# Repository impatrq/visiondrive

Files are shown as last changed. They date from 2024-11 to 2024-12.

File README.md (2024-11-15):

# VISION DRIVE: Innovacion en movimiento

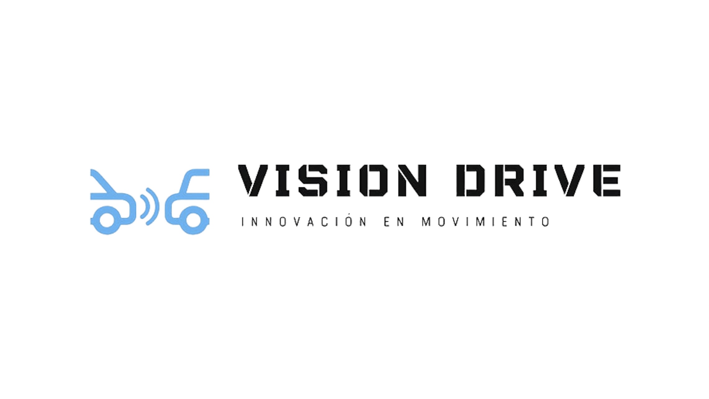
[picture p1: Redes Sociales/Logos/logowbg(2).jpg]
Descripción de la imagen


## Descripción del Proyecto

**Vision Drive** es un sistema diseñado para mejorar la seguridad y comodidad en la conducción mediante funciones de control de velocidad adaptativo y frenado de emergencia. Su propósito es reducir el esfuerzo del conductor y ofrecer un manejo más seguro.

## Características principales

- **Sistema de Control de Crucero Adaptativo (ACC)**: Permite al vehículo mantener una velocidad constante, ajustándose automáticamente en función de la distancia segura respecto a otros vehículos detectados en la misma vía.
- **Sistema de Emergencia Integrado**:  Este sistema monitorea el entorno en todo momento mientras el vehículo está en marcha. En situaciones de riesgo, como una frenada brusca de otro vehículo o la detección de una colisión inminente, el sistema activa el frenado automático.
- **Interfaz Adaptable**: Personalización según las necesidades del usuario.

## Tecnologías utilizadas

- **Sensor LiDar**: Para identificar la distancia del vehiculo de enfrente.
- **Sensor de Velocidad**: Para identificar la velocidad del vehiculo. 
- **ESP32** Para el procesamiento de datos.
- **C++ y Arduino IDE** Para el desarrollo del software 
- **Diseño PCB personalizado** para la integración de los componentes.
- **Motor Paso a Paso** Para el accionado del freno automatico.

## Estructura del Equipo

| Integrante | Responsabilidad |
|---|---|
| **Ponce Thiago** | Documentación y asistencia técnica |
| **Racioppi Giuliano**  | Programacion de los sensores |  
| **Meleri Thiago** | Diseño de las placas PCB |
| **Mazzoni Teo** | Código para los motores |
| **Suarez Simon** | Marketing |
| **Garofalo Thiago** | Diseño web y estructura |

## Contacto

- **Correo**: [Visiondriveimpa@gmail.com](mailto:visiondriveimpa@gmail.com)
- **Instagram**: (https://www.instagram.com/visiondrive24/)
- **Linktree**: (https://linktr.ee/visiondrive_2024)

*VISION DRIVE 2024 - Todos los derechos reservados*

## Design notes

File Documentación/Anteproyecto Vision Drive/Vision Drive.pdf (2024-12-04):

Escuela de Educación Técnica Nº7
Taller Regional Quilmes
Prácticas Profesionalizantes: Especialidad Aviónica

# VISION Drive

### Presentación de anteproyecto

Título del proyecto:

Elegimos como nombre del proyecto “VISION Drive” (Vehículo Inteligente con Sistemas Integrados de Orientación y Navegación) ya que transmite la esencia de un sistema de conducción avanzado que utiliza la visión como metáfora de la anticipación y la inteligencia del sistema, proporcionando a los conductores una herramienta poderosa para una conducción más segura y eficiente.

Integrantes:

- GAROFALO QUINTANA, Thiago: thiagogarofaloquintana@impatrq.com
- MAZZONI, Teo Jerónimo: teogeronimomazzoni@impatrq.com
- MELERI, Thiago Joaquín: thiagojoaquinmeleri@impatrq.com
- PONCE, Thiago Caín: thiagocainponce@impatrq.com
- RACIOPPI, Giuliano Daniel: giulianodanielracioppi@impatrq.com
- SUAREZ TUDISCA, Simón: simonsuareztudisca@impatrq.com
Objetivo del proyecto:

El objetivo principal del proyecto es crear un sistema capaz de mejorar la seguridad y la comodidad en la conducción de los vehículos de transporte, mediante la implementación de un sistema de control de crucero adaptativo y un sistema de emergencia integrado.

VISION Drive permitirá a los vehículos mantener una velocidad constante y segura en las vías de tránsito, ajustando automáticamente su velocidad para mantener una distancia de seguridad con respecto a los autos que se encuentren delante. Esto reduce la fatiga del conductor y mejora la eficiencia del viaje al adaptarse a las condiciones del tráfico de manera inteligente.

Este tiene un sistema de emergencia integrado el cual busca proporcionar una seguridad al detectar situaciones de riesgo inminente, como colisiones potenciales o frenadas bruscas de otros vehículos. En dichos casos, el sistema activará medidas de seguridad automáticas, como el frenado de emergencia o la emisión de alertas visuales y auditivas, para ayudar a prevenir accidentes o mitigar sus efectos.

Este enfoque busca contribuir a la mejora continua de la seguridad vial y la experiencia de transporte en entornos urbanos y de carretera.

Utilidades de el proyecto:

Las utilidades del proyecto de sistema de control de crucero adaptativo para el vehículo y sistema de emergencia pueden ser diversas y beneficiosas para diferentes sectores de la sociedad y entidades estratégicas:

Usuarios de VISION Drive:

- Facilita la conducción y reduce la fatiga del conductor evitando que el mismo esté pendiente a la aceleración y frenado del vehículo manteniendo una velocidad constante automáticamente. siendo muy útil en congestiones vehiculares de autopistas y calles mejorando la experiencia de manejo
- Incrementa la seguridad al ajustar automáticamente la velocidad en función de la distancia de seguimiento preventiva, ayudando a evitar accidentes por distracciones y acortando los tiempos de reacción
- El sistema de emergencia proporciona una alerta de seguridad al detectar y responder rápidamente a situaciones de riesgo, como colisiones potenciales, brindando tranquilidad a los ocupantes del vehículo

Entidades de transporte y logística:

- Mejora la eficiencia y la seguridad de las flotas de vehículos comerciales al reducir el riesgo de accidentes.

- Reduce los costos asociados con accidentes y mantenimiento al prevenir situaciones de emergencia o minimizando los daños recibidos .

Entidades de seguridad vial y reguladoras:

- Contribuye a la reducción de accidentes de tráfico y lesiones relacionadas al mejorar la capacidad de respuesta y la seguridad en la conducción.

Entidades de investigación y desarrollo tecnológico:

- Impulsa la innovación en el campo de la seguridad automotriz al integrar tecnologías avanzadas como el control de crucero adaptativo y los sistemas de emergencia en vehículos de transporte.

Descripción del funcionamiento:

Sistema de Control de Crucero Adaptativo (ACC):

Vision Drive comenzará a funcionar cuando el usuario seleccione la velocidad a la que quiere ir y presione el botón de funcionamiento

El sistema utilizará sensores (LiDAR) para detectar vehículos en la misma vía y calculará la distancia y la velocidad relativa con respecto a ellos.

Basándose en la información de los sensores, Vision drive ajustará automáticamente la velocidad del vehículo para mantener una distancia segura con los vehículos delanteros.

esta distancia de seguridad se estará constantemente monitoreando y dependiendo la velocidad a la que vaya el vehículo se seguirá una distancia correspondiente

El ACC también estará preparado para desactivarse automáticamente si el conductor aplica los frenos o interviene manualmente en la aceleración

Sistema de Emergencia Integrado:
- El sistema de emergencia estará activo en todo momento mientras el vehículo esté en funcionamiento.
- constantemente estará monitoreando los vehículos de enfrente y en caso de ocurrir una frenada brusca por parte del vehículo de enfrente, se ejecutará un frenado de emergencia con respuesta rápida.
- Cuando se detecte una situación de emergencia, el sistema activará automáticamente medidas de seguridad, como el frenado de emergencia, para evitar o mitigar el impacto de un accidente.
- El sistema de emergencia estará diseñado para ser robusto y confiable, minimizando los falsos positivos y asegurando una respuesta rápida y efectiva ante situaciones de peligro

Integración y Operatividad:
- Ambos sistemas, el ACC y el sistema de emergencia, estarán completamente integrados en el Melex, utilizando una arquitectura de control centralizada y eficiente.
- El software de ambos sistemas será altamente adaptable y configurable para ajustarse a las preferencias y necesidades específicas del conductor.
- Se proporcionará capacitación a los conductores para comprender y utilizar correctamente las funciones del ACC y el sistema de emergencia, así como para saber cómo actuar en caso de una intervención manual necesaria o una situación de emergencia.

En conclusión, la funcionalidad del proyecto se centra en implementar tecnologías avanzadas que mejoren la seguridad y la comodidad en la conducción del Melex, garantizando una operación efectiva y confiable del sistema de control de crucero adaptativo y el sistema de emergencia integrado.

Análisis de factibilidad:

Alumno 1: SUAREZ TUDISCA, Simón

- Diseño:
- Lista de Requisitos: Su primera tarea será elaborar una lista detallada de todos los elementos necesarios para el proyecto. Esto incluirá componentes técnicos como el sensor Lidar, así como también elementos de diseño como el logotipo, la estructura de la página web y cualquier otro recurso necesario para el funcionamiento y la presentación del proyecto.
- Diseño de la Estructura: Se encargará de diseñar la estructura general del proyecto, incluyendo la arqmfy funcionalidad de la página web, y la integración de elementos de marketing como banners o material promocional.
- Diseño del Logotipo: Será responsable de crear el diseño del logotipo del proyecto, asegurándose de que refleje adecuadamente la identidad y los valores del mismo.
- Marketing: Colaborará en la estrategia de marketing del proyecto, contribuyendo con ideas y diseñando material promocional, como folletos, carteles, redes sociales, etc., para dar a conocer el proyecto y sus beneficios de manera efectiva.

Alumno 2: RACIOPPI, Giuliano Daniel
Alumno 3: MELERI, Thiago Joaquín
- La estructura: Reacondicionamiento de los dos melex para su correcto funcionamiento.
Problemas que ya tenemos que arreglar:

En uno de los dos Melex hay que cambiar el liquido de freno.Además de las baterías que ya sabemos que hay que cambiarlas.También en un carro hay que arreglarle la controladora.Otro problema que tenemos es que en un Melex el motor no tiene un correcto funcionamiento
Además de los problemas que tengamos que reparar a lo largo del proyecto
Instalación de los elementos del sistema que vamos hacer y ajuste en el software para que cada elemento funcione correctamente según lo planificado.

Alumno 4: MAZZONI, Teo Jeronimo
Alumno 5: GAROFALO, Thiago Ariel
Alumno 6: PONCE, Thiago Caín
- Programación:

La programación desempeñará un papel fundamental en este proyecto, ya que debemos desarrollar un programa viable para el sensor Lidar. Esto implica controlar la velocidad del carrito y mantenerla constante, además de garantizar que la velocidad permita suficiente tiempo de frenado en caso de que sea necesario detenerse rápidamente debido a la presencia de un carro adelante. En consecuencia, se requerirá un programa completo que abarque tanto el control del acelerador como el sistema de frenos del carrito.

Alumno 4:Teo Mazzoni
Diseño en Máquinas 3D:

En este proyecto va ser necesario hacer piezas necesarias en máquina 3D,como una tapa para el volante,soporte para las cámaras y demás.

Costo del proyecto:

Componentes:

- Baterías x6 (financiadas por fuerza área)

- Sensor distancia rango LiDAR (179 usd)
- Mini servo tower pro Sg90 x2 (6 usd)
- Pantalla lcd. Velocidad seleccionada (7 usd)
- Botones pulsadores x4 (3,5 usd)
- Esp 32 (16usd)
- Fin de carrera (2 usd)
- Liquido de freno 500ml (9,5 usd)
- Fuente para alimentar esp 32 (6 usd)
- Cables

Costo total del proyecto: 229 USD

Referencias:

- Sensor distancia rango LiDAR

https://articulo.mercadolibre.com.ar/MLA-1414544053-sensor-distancia-rango-lidar-tfmini-s-tf-mini-_JM (https://articulo.mercadolibre.com.ar/MLA-1414544053-sensor-distancia-rango-lidar-tfmini-s-tf-mini-_JM)

- Mini servo tower pro Sg90 x2 (6 usd)

https://articulo.mercadolibre.com.ar/MLA-1407455153-mini-servo-tower-pro-sg90-9g-robotica-servomotor-arduino-_JM (https://articulo.mercadolibre.com.ar/MLA-1407455153-mini-servo-tower-pro-sg90-9g-robotica-servomotor-arduino-_JM)

- Pantalla lcd. Velocidad seleccionada

https://articulo.mercadolibre.com.ar/MLA-880040960-display-pantalla-lcd-16x2-con-i2c-incorporado-para-arduino-_JM (https://articulo.mercadolibre.com.ar/MLA-880040960-display-pantalla-lcd-16x2-con-i2c-incorporado-para-arduino-_JM)

- Botones pulsadores

https://articulo.mercadolibre.com.ar/MLA-1394810047-boton-pulsador-push-button-tact-switch-12x12x5mm-pack-x5-_JM (https://articulo.mercadolibre.com.ar/MLA-1394810047-boton-pulsador-push-button-tact-switch-12x12x5mm-pack-x5-_JM)

- Esp 32

https://articulo.mercadolibre.com.ar/MLA-916790826-nodemcu-esp32-wifi-bluetooth-42-iot-wroom-esp32s-arduino-_JM (https://articulo.mercadolibre.com.ar/MLA-916790826-nodemcu-esp32-wifi-bluetooth-42-iot-wroom-esp32s-arduino-_JM)

- Fin de carrera

https://articulo.mercadolibre.com.ar/MLA-1297548912-micro-switch-fin-carrera-con-leva-y-rueda-5a-250v-3d-cnc-_JM (https://articulo.mercadolibre.com.ar/MLA-1297548912-micro-switch-fin-carrera-con-leva-y-rueda-5a-250v-3d-cnc-_JM)

- Líquido de freno

https://www.mercadolibre.com.ar/liquido-para-frenos-tipo-3-500ml-wagner-lockheed-130024/p/MLA24952895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 a82-b966-81cf93632560 (https://www.mercadolibre.com.ar/liquido-para-frenos-tipo-3-500ml-wagner-lockheed-130024/p/MLA24952895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)

- Fuente para alimentar esp32:

https://articulo.mercadolibre.com.ar/MLA-1141509051-fuente-step-down-acdc-8-24v-salida-dc-5v-12a-lm7805-_JM (https://articulo.mercadolibre.com.ar/MLA-1141509051-fuente-step-down-acdc-8-24v-salida-dc-5v-12a-lm7805-_JM)

Análisis de costo/beneficio:

Reducción de accidentes y lesiones: VISION Drive puede ayudar a reducir muchos accidentes y lesiones en la carretera. Esto significa menos personas heridas y menos dinero gastado en hospitales y seguros. Al mejorar la seguridad, muestra que la empresa se preocupa por la seguridad de sus empleados y clientes.

Mejora en la experiencia de conducción: VISION Drive hace que conducir sea más fácil y seguro. Esto hace que los conductores se sientan más cómodos y seguros al volante. Además, cuando un producto es más fácil de usar y hace que la vida sea mejor, la gente tiende a hablar bien de la empresa que lo fabrica.

Sistema de emergencia: El sistema de emergencia estará diseñado para ser robusto y confiable, minimizando los falsos positivos y asegurando una respuesta rápida y efectiva ante situaciones de peligro.

Comparación con el estado actual y por qué replicar VISION Drive:

Los controles de cruceros adaptativos actualmente cuando detectan otro auto en una situación de tráfico o algún objeto se frenan a 0 y no retoman su marcha, mientras que Vision Drive tendrá la capacidad de mantener una marcha continua automáticamente mejorando la experiencia de manejo reduciendo el estrés en situaciones de tráfico denso. En estos momentos la seguridad y la comodidad en la conducción dependen de la habilidad y atención del conductor, Si por ejemplo el conductor de un carro melex se queda dormido o tiene otro vehículo cerca y no llega a reaccionar podría resultar en accidentes. VISION Drive ofrece una solución tecnológica que automatiza y mejora estos aspectos, lo que significa un beneficio en ahorrar costos asociados con accidentes, lesiones, además de lo que significa que se lastime una persona.

Diagrama de bloques:

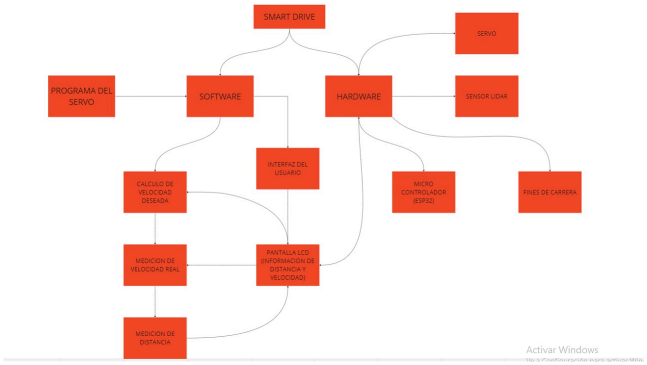
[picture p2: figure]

Diagrama de tiempo de desarrollo:

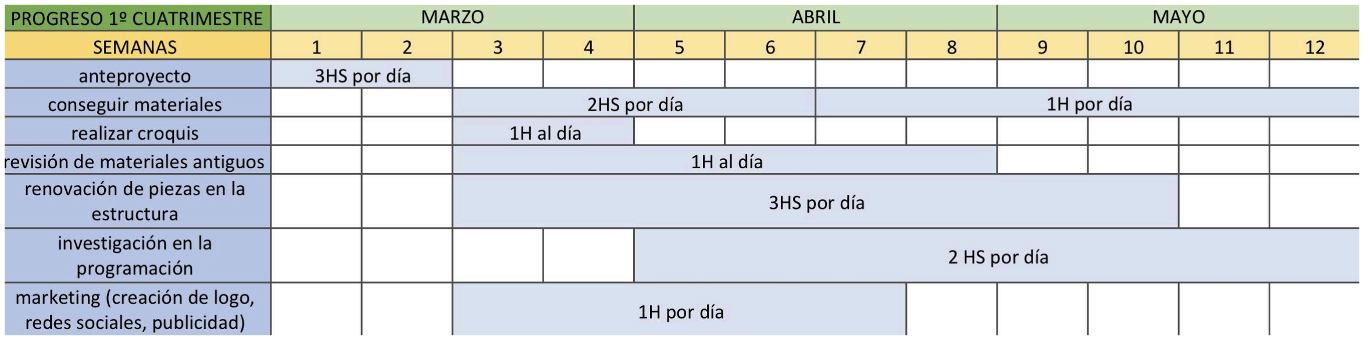
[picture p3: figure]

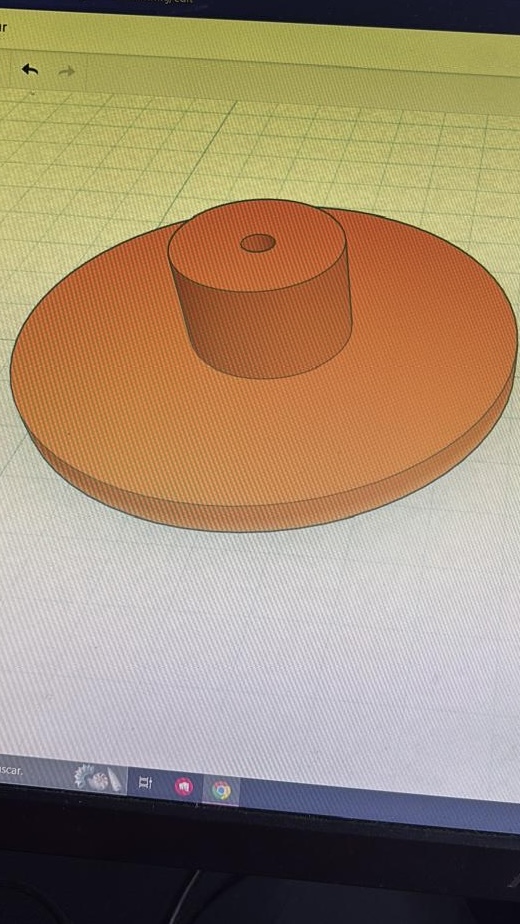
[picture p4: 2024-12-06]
Impresiones 3D/Diseños de piezas 3d/diseño de primer pieza 3d .jpg.jpeg

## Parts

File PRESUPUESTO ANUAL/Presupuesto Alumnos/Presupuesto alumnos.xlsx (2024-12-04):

Tipo de Material | cantidad | costo | Costo Total
Esp32 wifi+bluetooth | 1 | $10152.00 | $94117.50
Liquido de freno | 1 | $13657.00
Transistores | 4 | $3000.00
Bulones con Tuercas | 1 | $4000.00
Juego De Llaves Combinadas (Para uso personal de los alumnos) | 1 | $12338.99
Transistor Irlz44n | 2 | $3704.84
Transistor p75nf75 | 1 | $2806.70
Modulo regulador de voltaje stepdown | 3 | $10104.12
Fin de Carrera | 2 | $3031.24
Placa de Cobre 15x15 | 1 | $3872.48
Octoacoplador 4n135 | 2 | $4041.65
Temporizador 555 | 1 | $1091.45
Resistencia 1k | 1 | $377.57
Potenciometro 5k | 3 | $3520.62
Capacitor 1nf | 2 | $188.71
Capacitor 22nf | 2 | $280.78
Capacitor 100nf | 2 | $406.56
Diodo 1n4001 | 4 | $309.32
Placa de Cobre 20x15 | 1 | $7102.71
Mosfet IRFZ44 | 2 | $4322.54
Timer LM555 | 2 | $2182.90
Led 6N135 | 1 | $3625.32

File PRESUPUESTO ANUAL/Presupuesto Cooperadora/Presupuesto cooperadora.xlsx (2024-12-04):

Tipo de Material | cantidad | costo | Total
Motor Paso a Paso nema 34 | 1 | $140.950 | $397963.00
Microstep Driver DM556 | 1 | $90000.00
Sensor LiDar | 1 | $89000.00
Display lcd 16x2 | 1 | $6000.00
Botón pulsador switch negro | 5 | $1300.00
Sensor de Velocidad | 1 | $4599.00
Modulo fuente step down | 4 | $15476.00
Caño de freno trasero con virola | 1 | $25000.00
Bornera 3 pines paso a paso | 1 | $8159.00
Bornera 2 pines paso a paso | 1 | $6079.00
Esp32 wifi+bluetooth | 1 | $11399.00

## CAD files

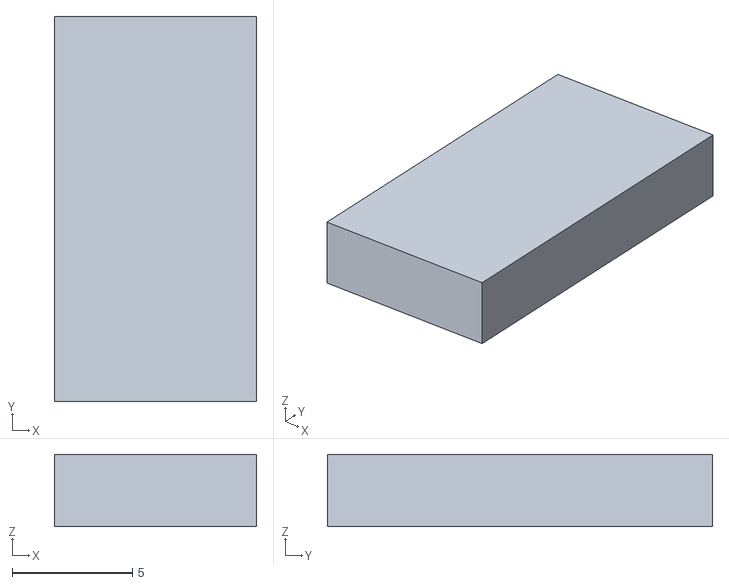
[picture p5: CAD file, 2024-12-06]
Impresiones 3D/Piezas 3D/Pieza 3d Caja protector de placa.stl
8.40 x 16.0 x 3.00

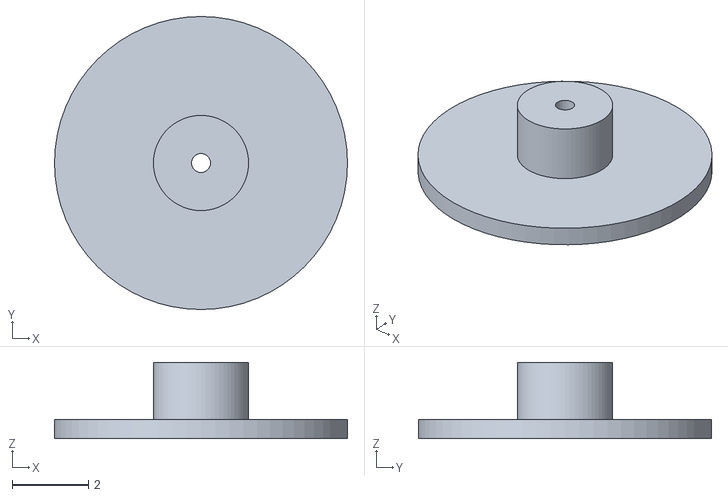
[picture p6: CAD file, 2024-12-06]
Impresiones 3D/Piezas 3D/Stunning Duup-Jaiks.stl
7.70 x 7.70 x 2.00

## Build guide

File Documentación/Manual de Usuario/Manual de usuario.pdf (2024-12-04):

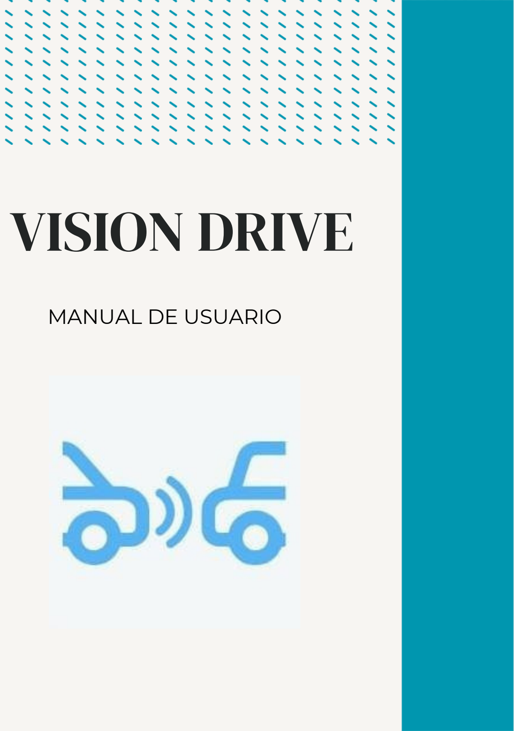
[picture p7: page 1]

# VISION DRIVE

# MANUAL DE USUARIO

# INDICE

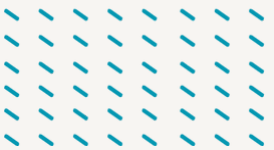
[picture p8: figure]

VISION DRIVE | 01

# Introducción

# Configuracion inicial del Sistema

# Mantenimiento y Solución de Problemas

# Preguntas Frecuentes (FAQ) Recursos

# Adicionales y Contacto

# INTRODUCCION

### Vision Drive es un sistema diseñado para mejorar la

### seguridad y comodidad en la conducción mediante

### funciones de control de velocidad adaptativo y frenado de

### emergencia. Su propósito es reducir el esfuerzo del

conductor y ofrecer un manejo más seguro.

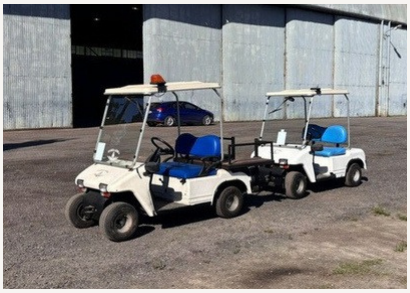
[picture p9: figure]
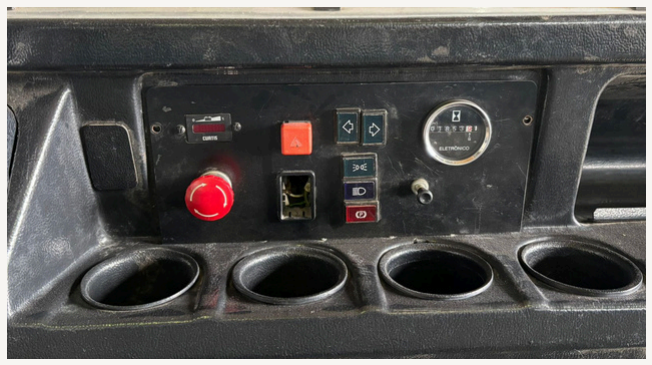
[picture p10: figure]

### Enlace a Vídeos Tutoriales

### NOSOTROS SOMOS VISION DRIVE

### https://youtu.be/LOYh_ITEwog?si=ThBYP7wRfd70sf3Y

### Video tutorial Control Crucero Adaptativo https://youtu.be/mBXZGiRCk4A?si=qK7LPOu4xnHvmMUh VIdeo Tutorial Sistema de Frenado https://youtu.be/ewcQx7pID0I?si=PtU2gTBYoK5jmtBM

Sistema de Control de Crucero Adaptativo (ACC) El ACC ajusta automáticamente la velocidad del vehículo para mantener una distancia segura con el automóvil de adelante, utilizando sensores para frenar o acelerar según el tráfico. Esto reduce la necesidad de ajustes constantes del conductor y mejora la seguridad en trayectos largos. Sistema de Frenado de Emergencia Autonomo (AEB) El AEB frena automáticamente el vehículo si detecta un obstáculo o riesgo de colisión inminente y el conductor no reacciona a tiempo. Esto ayuda a prevenir accidentes y protege tanto al conductor como a otros vehículos en situaciones imprevistas.

### Vision Drive esta conformado por dos Sistemas

1.Ubicación del sistema: Ubica la interfáz de usuario , este se encuentra en el panel del carro , al lado derecho del volante . Esta conformado por una pantalla táctil ( dispositivo/tableta ). 2.La interfáz de Usuario se encenderá con dos toques en su pantalla.
3. Una vez encendida la pantalla , mostrará dos opciones que serán “ON” (Encendido del sistema) “OFF” (Apagado del sistema), que estan alternados en un mismo pulsador y una barra horizontal en la parte inferior de la interfáz que sirve para regular la velocidad del Sistema de Control Crucero.

# CONFIGURACIÓN INICIAL DEL SISTEMA

Sigue estos sencillos pasos para configurar Vision Drive y comenzar a disfrutar de sus beneficios de manera segura y eficiente. Este proceso no toma mucho tiempo y te guiará a través de las configuraciones básicas del sistema.
Paso 1: Ubicar el Sistema

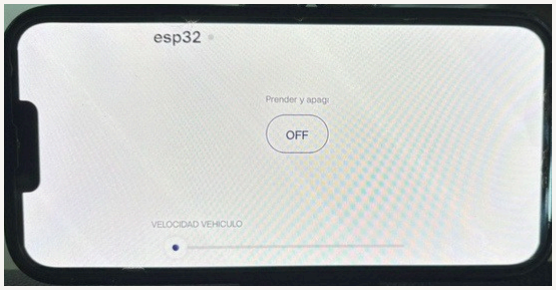
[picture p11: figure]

Paso 2: Encender el sistema Vision Drive Enciende el Sistema tocando el pulsador ,que en ese momento estará en “OFF”

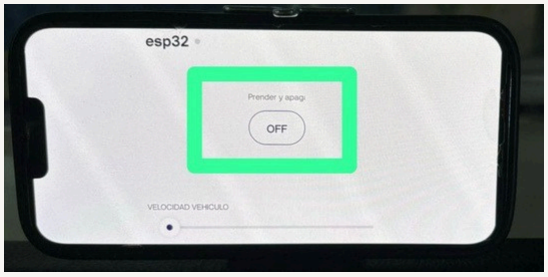
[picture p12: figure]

Al pulsar en “OFF” cambiará su estado a “ON”, encendiendo el sistema.

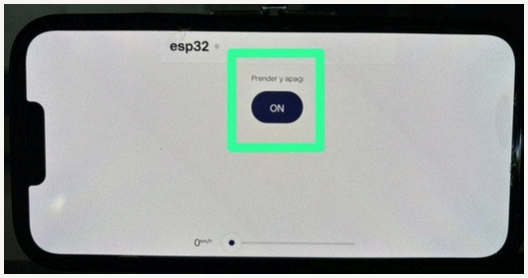
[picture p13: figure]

Una vez encendido el sistema ,selecciona la velocidad a la que el usuario desee ir , esto se hace con la barra horizontal que se encuentra en la interfáz de usuario. La velocidad minima es de 1km/h. La velocidad maxima es de 25km/h.

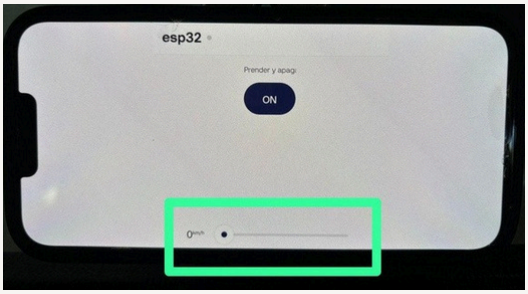
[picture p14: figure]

El sistema de frenado autonomo no requiere ninguna configuración del usuario , este se activará automaticamente en caso de riesgo de colisión o peligro inminente, iniciando una etapa de frenado gradual hasta detenerse antes de colisionar con el objeto.

Sistema de Frenado Autonomo

Sistema de Frenado Manual

El frenado manual esta disponible, se tiene que presionar pedal de freno ubicado en la pedalera que se ubica al lado de el pedal de aceleradorl.

# Mantenimiento y Solución de

# Problemas

Mantén Vision Drive en óptimas condiciones y soluciona problemas comunes con estos sencillos pasos.

Mantenimiento Básico

Limpieza de sensor LiDAR Revisa que el sensor LiDAR esté limpio y libre de polvo, suciedad o cualquier obstrucción que pueda afectar su precisión. Limpia suavemente con un paño de microfibra y, si es necesario, utiliza un producto de limpieza para lentes electrónicos. El sensor LiDar se encuentra instalado en la parte delantera del vehículo.

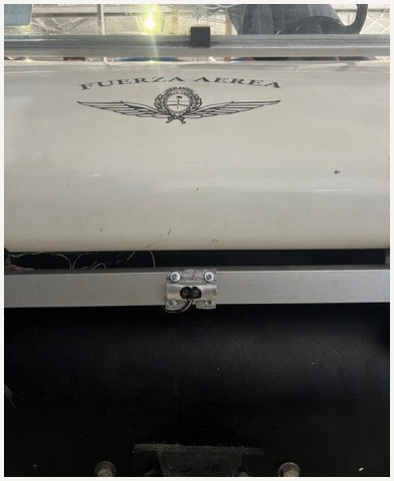
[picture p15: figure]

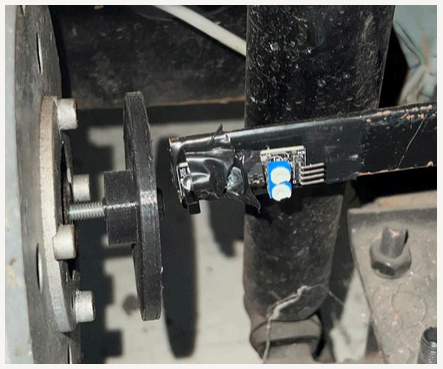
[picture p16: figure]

Asegúrate de que las conexiones eléctricas estén firmes y libres de corrosión. Esto es esencial para evitar problemas de comunicación entre los sistemas del vehículo.

Verificación de Conexiones

Revisar conexiones del sensor LiDar

Sensor de Velocidad
Realiza el mismo mantemiento con el sensor de velocidad, este se ubica en el chasis , del lado derecho de la rueda trasera.

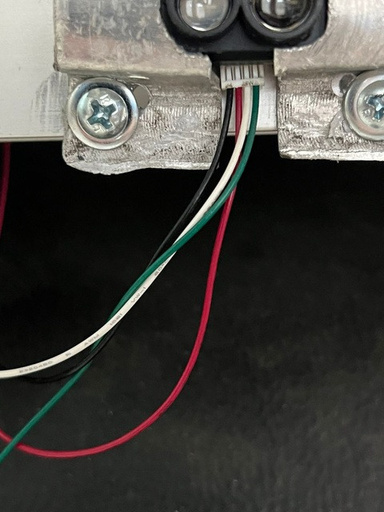
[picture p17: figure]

Revisar conexiones del Driver

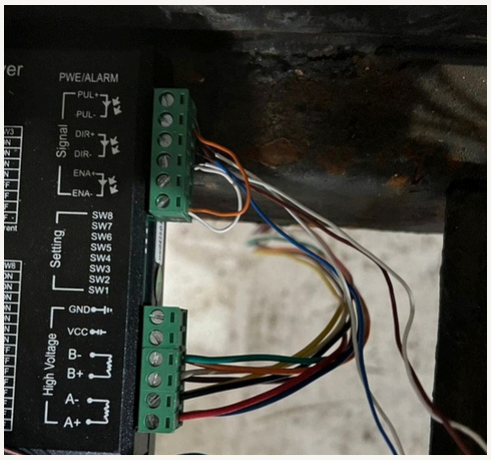
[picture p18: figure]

Neumáticos

Ante un desperfecto de la cubierta, proceda a cambiar la rueda utilizando el auxilio provisto junto con su vehículo, colocando el crique en el lugar indicado en la figura.

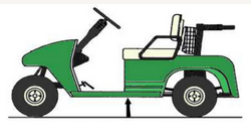
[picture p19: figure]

ADVERTENCIA: Controle periódicamente la presión de los neumáticos.

Presiones recomendadas:
Neumáticos Delanteros 23 PSI
Neumáticos Traseros 24 PSI

Tareas de Mantenimiento Preventivo que debe realizarle a su Vehículo

Todos los días:

- Controlar el estado de carga de las baterías.
- Controlar la presión de los neumáticos.
- Controlar el correcto funcionamiento de los frenos, antes de utilizar el vehículo.

Una vez por semana:

- Controlar el nivel del agua de las baterías.
- Limpiar tapas y bornes de las baterías.

Una vez por mes:

•Verificar que no haya cables rotos o sueltos y conexiones eléctricas flojas

. • Ajustar las conexiones eléctricas si estuvieran flojas.

- Revisar ficha macho en el cargador de baterías y hembra en el vehículo.
- Limpiar y aceitar los cables del freno.

Una vez al año

- Revisar los retenes de los palieres y de las puntas de eje.
- Revisar los bujes del tren delantero.
- Revisar el libre movimiento de todos los rulemanes.
- Revisar el nivel de aceite en la barra de dirección.
- Hacer el recambio del aceite en el diferencial.
- Revisar el juego de los engranajes de la transmisión.
- Revisar los carbones del motor.
- Revisar los elásticos y amortiguadores.
- Revisar si no están arruinadas las alfombras, las molduras y los cubre pedales.

Cada seis meses:

- Limpie y lubrique los contactos móviles de la palanca selectora de marcha.
- Revisar alineación ruedas delanteras.

Cada tres meses:

- Revisar el nivel del aceite en el diferencial, agregar de ser necesario. (ACEITE PARA DIFERENCIAL 140).
- Controle y limpie el venteo del diferencial.
- Verificar la columna de dirección.

Guia de Carga

1. Apaga el vehículo: Asegúrate de que el vehículo esté completamente apagado.
2. Conecta el cargador: Inserta el cable del cargador en el conector. Conecta el positivo del cargador al positivo de la batería. Conecta el negativo del cargador al negativo de la batería. Configura el cargador: Ajusta el voltaje a 24V y la corriente a 33A.

BATERIAS

El vehiculo eléctrico esta equipado con 2 baterías Niquel Cadmio de 24V y 33A que garantizan su funcionamiento.

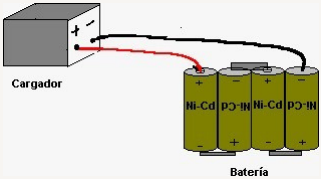
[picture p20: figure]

3. Inicia la carga: Enciende el cargador y verifica que el proceso de carga haya comenzado.
4. Supervisa la carga: Revisa periódicamente el estado de las baterías para evitar sobrecalentamiento.
5. Desconecta al finalizar: Cuando la carga esté completa, apaga el cargador y retira el cable con cuidado.

Pruebas de Funcionamiento

Precauciones y Advertencias
No cargues las baterías en ambientes húmedos o cerca de materiales inflamables.
Utiliza únicamente cargadores compatibles y en condiciones óptimas.
Si notas daños o anomalías en las baterías, interrumpe el proceso y contacta con soporte técnico.

Luego de realizar el mantenimiento del sistema , haz una prueba del sistema Vision Drive en un entorno seguro. Asegúrate de que el ACC responde correctamente a los cambios en la distancia y que el Frenado de Emergencia se activa cuando detecta un obstáculo.

# Preguntas Frecuentes (FAQ)

1. ¿Cómo sé si el Control de Crucero Adaptativo (ACC) está funcionando correctamente?
Verás el icono de ACC activo en la pantalla y notarás que ajusta la velocidad del vehículo automáticamente según la distancia de seguridad con otros vehículos.
2. ¿El Sistema de Emergencia se activa sin intervención?
Sí, este sistema detecta frenadas bruscas de otros vehículos y activa el frenado de emergencia automáticamente para mejorar la seguridad.
3. ¿Qué debo hacer si el sistema no responde o se congela?
Apaga el sistema y vuelve a encenderlo. Si persiste el problema, revisa las conexiones y verifica si hay algun componente en mal estado.
4. ¿Cada cuánto debo limpiar los sensores LiDAR?
Se recomienda limpiar los sensores semanalmente para asegurar que detecten la distancia y obstáculos con precisión.
5. ¿Vision Drive funciona bien en todas las condiciones climáticas? El sistema está diseñado para distintas condiciones, pero en casos de lluvia intensa o nieve, algunos sensores pueden ver reducida su eficacia. Ten precaución en estos casos.

# RECURSOS ADICIONALES

Integrantes

Soporte Tecnico

Telefono
+54 9 11 2829-6905
Correo Electronico
Visiondriveimpa@gmail.com

Actualizaciones y
Descargas

Comunidad en Linea

Redes Sociales
https://linktr.ee/visiondrive_2024
Github
https://github.com/orgs/impatrq/teams/visiondrive Trello
https://trello.com/b/eQXwQucZ/kanban

VISION DRIVE

Ponce Thiago Cain
Suarez Tudisca Simon
Mazzoni Teo Geronimo
Garofalo Thiago Ariel
Meleri Thiago Joaquin
Racioppi Giuliano Daniel

01

https://vision-drive.github.io/

Consulta la página de descargas en nuestro sitio web para obtener actualizaciones de software y mejoras del sistema

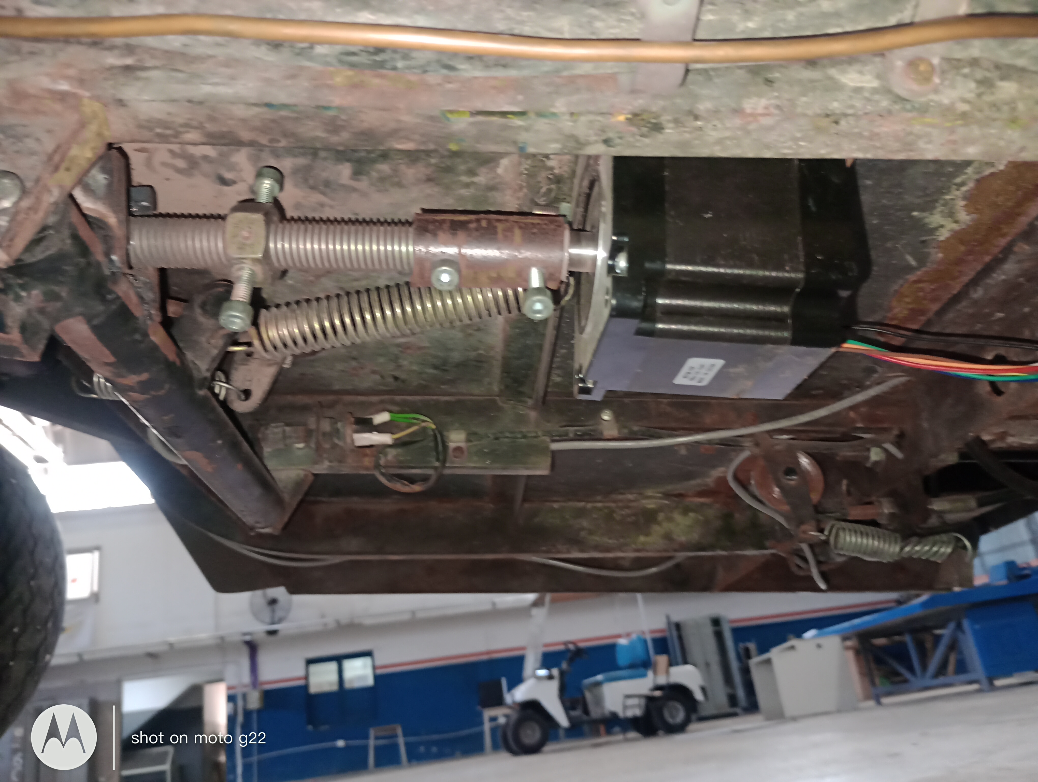
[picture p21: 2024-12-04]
Carros Melex/Armado/Armado motor Paso a Paso/IMG_20241202_103750067.jpg

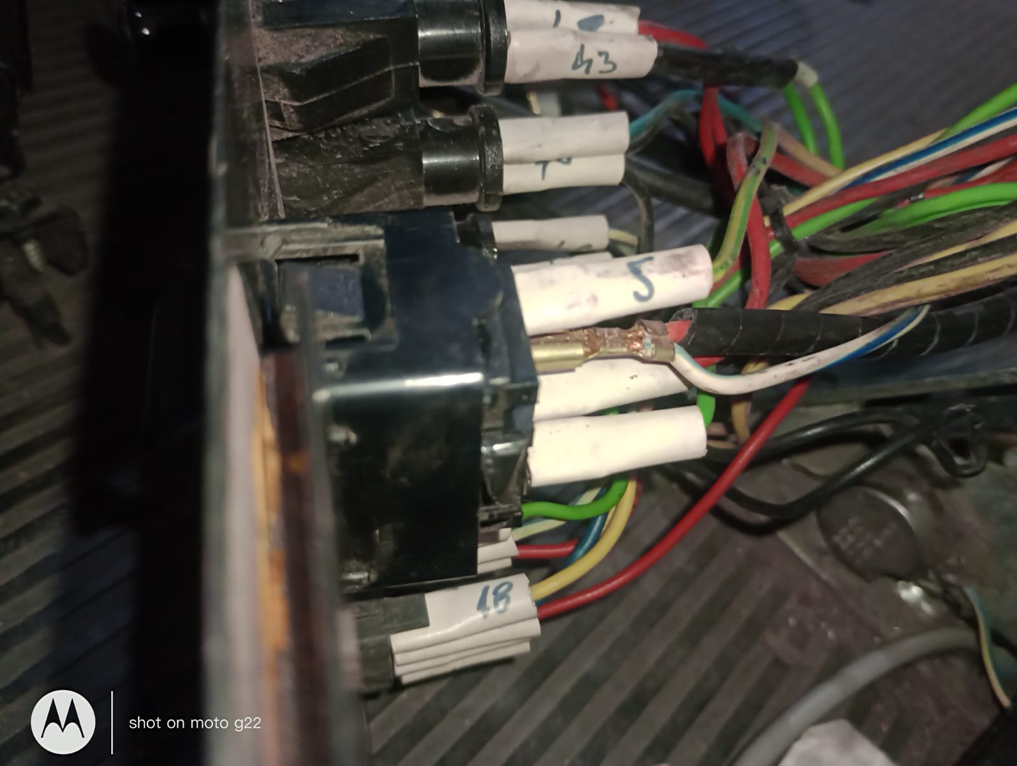
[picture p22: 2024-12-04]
Carros Melex/Armado/tablero de luces/Imagen de WhatsApp 2024-11-15 a las 22.40.53_919cac17.jpg

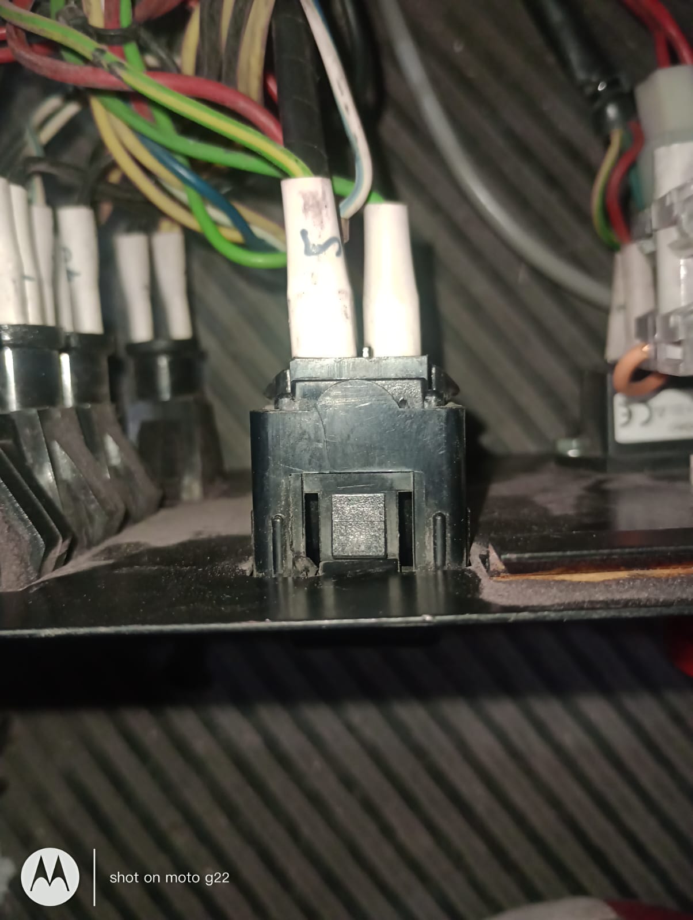
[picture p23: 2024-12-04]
Carros Melex/Armado/tablero de luces/Imagen de WhatsApp 2024-11-15 a las 22.40.54_3493a4e6.jpg

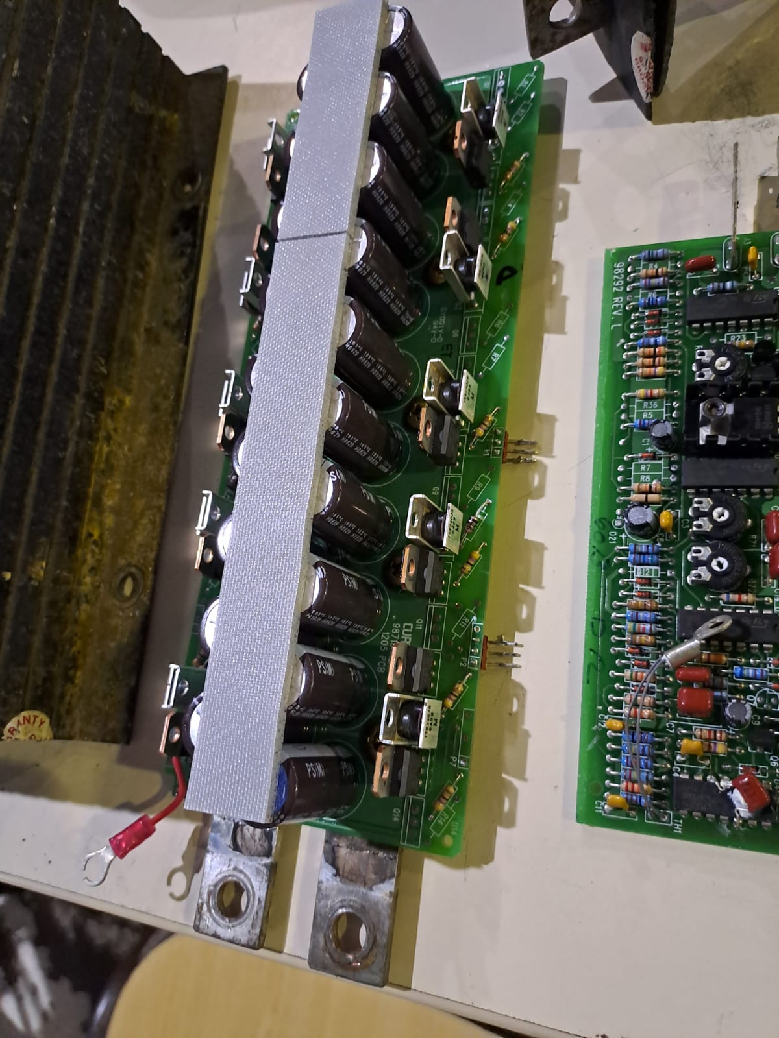
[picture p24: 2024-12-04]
Carros Melex/Armado/Controladora/Imagen de WhatsApp 2024-11-14 a las 22.56.10_7051b5ce.jpg

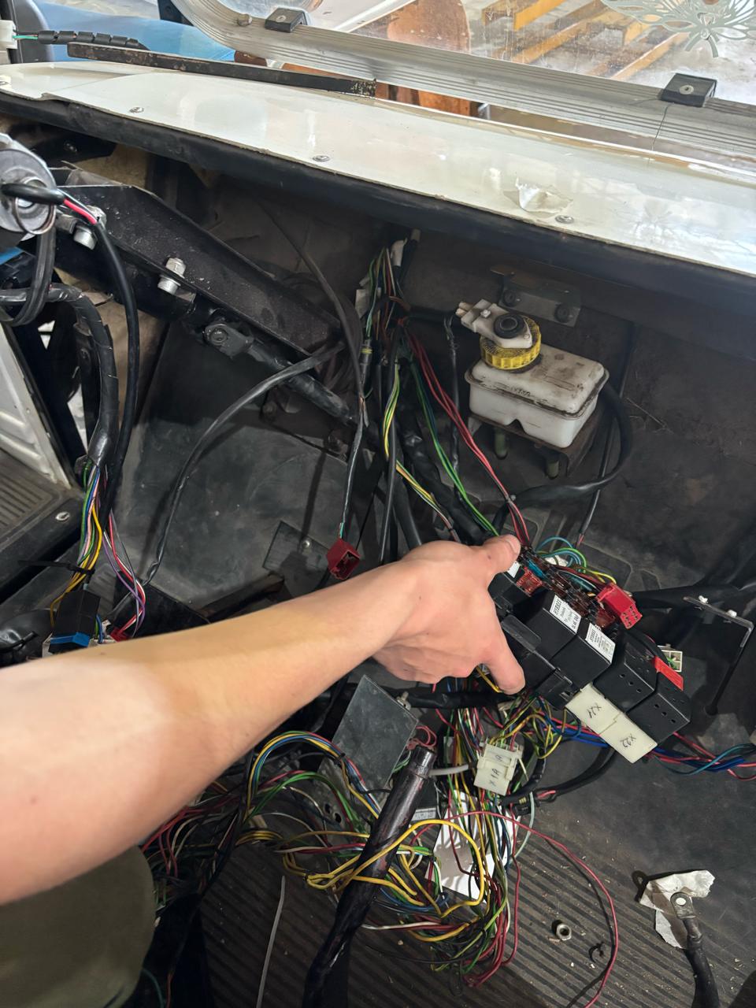
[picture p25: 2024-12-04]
Carros Melex/Armado/Cableado de luces/Imagen de WhatsApp 2024-11-14 a las 22.21.11_0682b30c.jpg

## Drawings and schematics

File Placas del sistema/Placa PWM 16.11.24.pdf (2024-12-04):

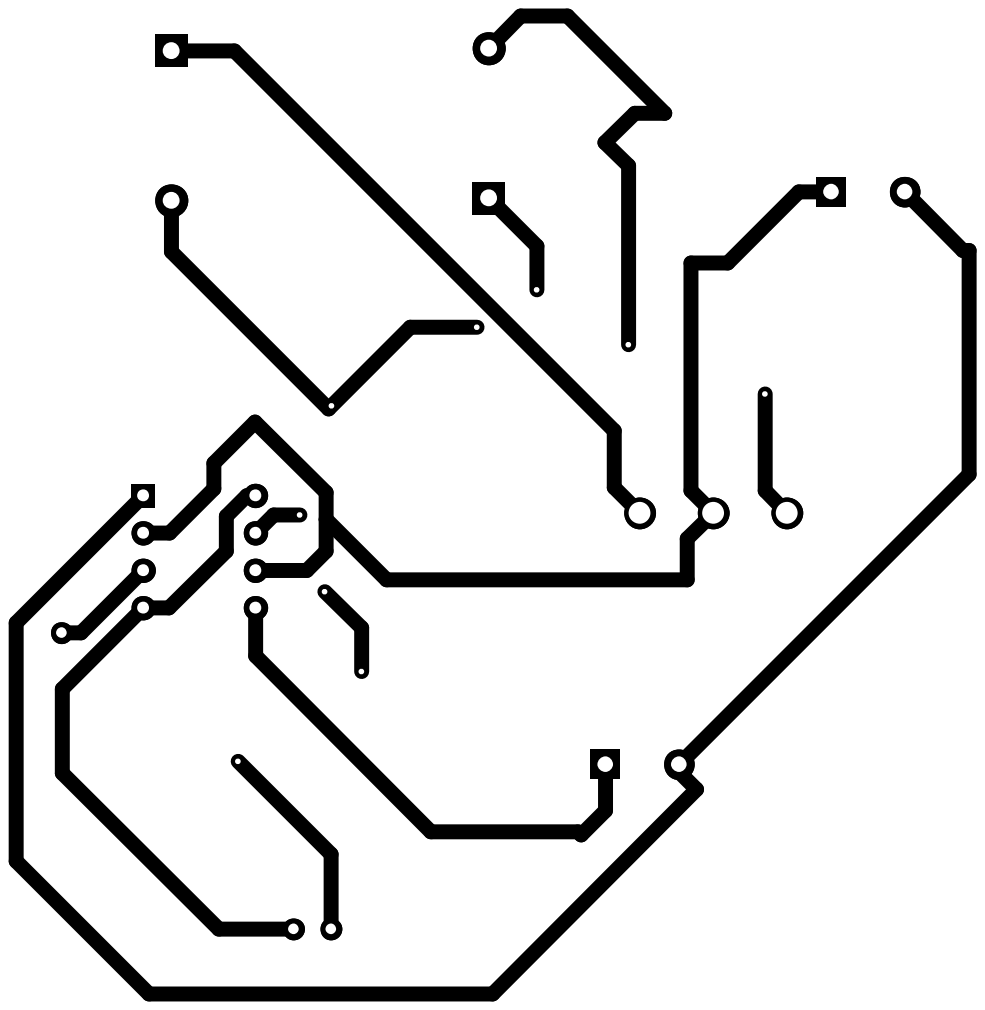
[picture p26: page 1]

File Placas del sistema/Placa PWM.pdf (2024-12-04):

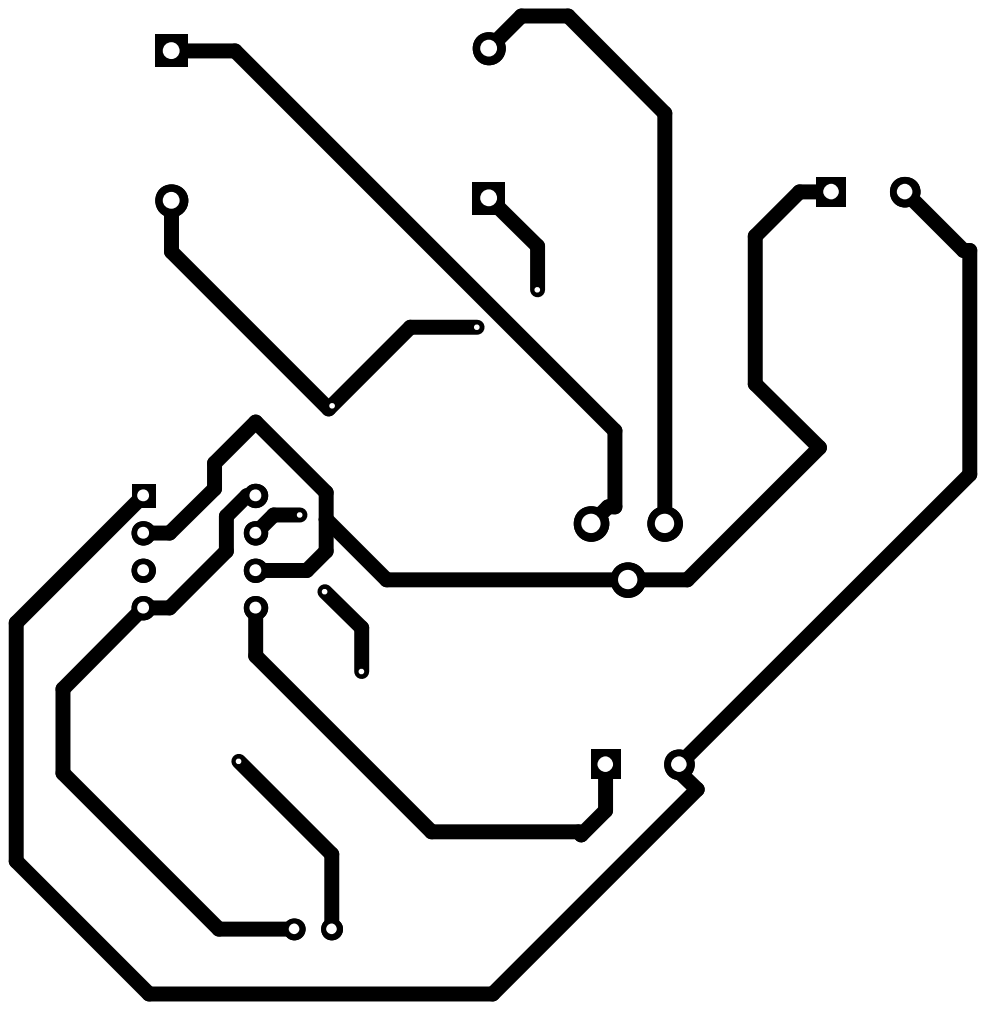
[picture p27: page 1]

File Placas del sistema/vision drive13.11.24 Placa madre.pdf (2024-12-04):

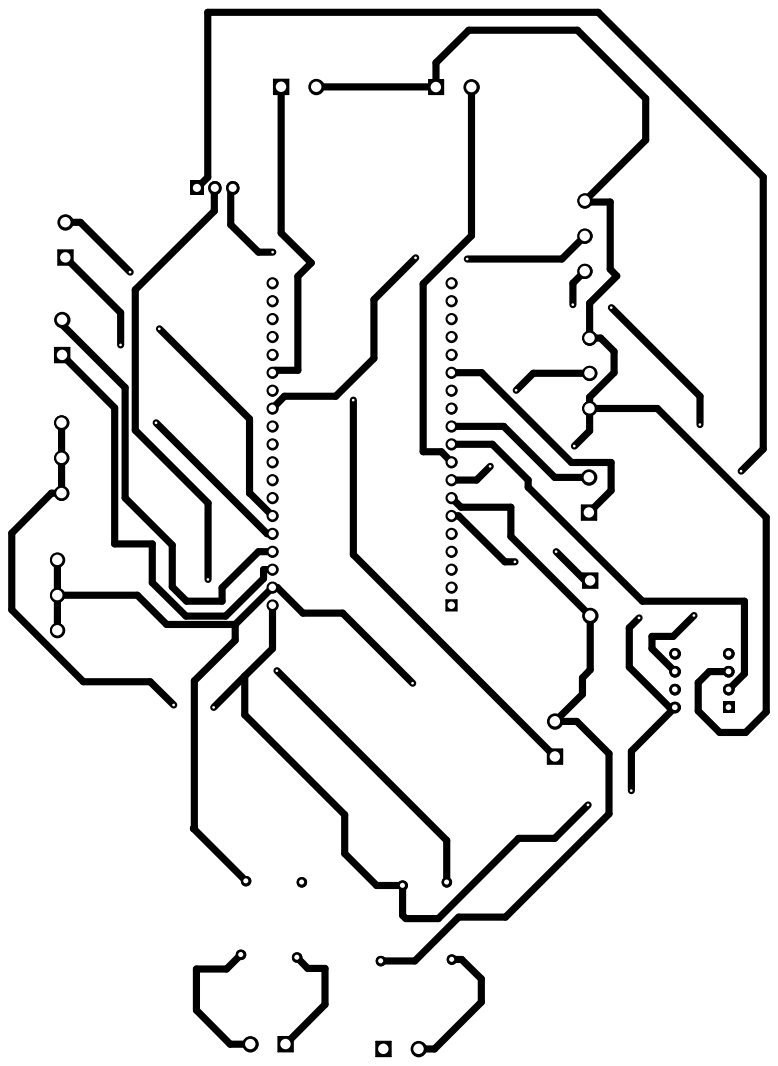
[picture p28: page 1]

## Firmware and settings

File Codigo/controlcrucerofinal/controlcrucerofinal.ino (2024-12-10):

#define BLYNK_TEMPLATE_ID "TMPL2qhiOVqKL"
#define BLYNK_TEMPLATE_NAME "Prender y apagar"
#define BLYNK_DEVICE_NAME "esp32"
#define BLYNK_AUTH_TOKEN "z_WQQExctXxZYm90cLcXuyi1n2bwjFtm"

#include <WiFi.h>
#include <BlynkSimpleEsp32.h>
#include <PID_v1.h>

// Pines físicos
const int motorStepPin = 19;  // Pin de paso del motor paso a paso (freno)
const int motorDirPin = 25;   // Pin de dirección del motor paso a paso
const int lidarRXPin = 16;    // Pin RX del sensor LiDAR
const int lidarTXPin = 17;    // Pin TX del sensor LiDAR
const int speedSensorPin = 5; // Pin del sensor infrarrojo de velocidad
const int finDeCarreraPin = 14; // Pin del fin de carrera para resetear freno

// Parámetros del motor paso a paso
const int stepsPerRevolution = 6400; // 6400 micropasos por revolución (DM 556)
const float avancePorVuelta = 1.905; // Avance del freno por vuelta de la varilla ACME (cm)
const float maxFreno = 10.0;  // Recorrido máximo del freno (10 cm)

// Control de velocidad del motor paso a paso
const int fastSpeed = 40;     // Velocidad rápida del motor (en microsegundos)
const int mediumSpeed = 80;   // Velocidad media del motor
const int slowSpeed = 160;    // Velocidad lenta del motor

// Parámetros PID para frenado
double setPointDist, inputDist, outputFreno;
double Kp = 2.0, Ki = 5.0, Kd = 1.0; // Ajusta estos valores para tu sistema
PID frenadoPID(&inputDist, &outputFreno, &setPointDist, Kp, Ki, Kd, DIRECT);

// Parámetros PID para control de velocidad
double setPointVel, inputVel, outputVel;
double KpVel = 1.0, KiVel = 0.5, KdVel = 0.1; // Ajusta estos valores para tu sistema
PID velocidadPID(&inputVel, &outputVel, &setPointVel, KpVel, KiVel, KdVel, DIRECT);

// Estado del sistema
bool controlDeCrucero = false; // Indica si el control de crucero está activado
int selectedSpeed = 0; // Velocidad seleccionada por el usuario
int maxSpeed = 25; // Velocidad máxima en km/h (25 km/h)

// Variables de velocidad y distancia
int velocidadActual = 0;
int distanciaSegura = 50; // Distancia mínima segura en cm para comenzar a frenar
int distanciaAnterior = 0; // Para calcular la velocidad de acercamiento

// Variables para LiDAR
int dist;  // Distancia medida por el LiDAR
unsigned long lastLidarTime = 0; // Última vez que se midió la distancia
unsigned long lidarInterval = 100; // Intervalo de tiempo entre lecturas del LiDAR (en ms)

// Variables para sensor infrarrojo (velocidad)
unsigned long lastSpeedTime = 0; // Último tiempo registrado por el sensor
unsigned long currentSpeedTime = 0;
int numPulsos = 0; // Contador de pulsos para medir la velocidad

// Distancias de seguridad según la velocidad seleccionada
int distanciasSeguras[26] = {0, 5, 10, 15, 20, 25, 30, 35, 40, 45, 50, 
                             55, 60, 65, 70, 75, 80, 85, 90, 95, 100, 
                             105, 110, 115, 120, 125}; // En cm, ajustar según sea necesario

// Definición de pines virtuales Blynk
char auth[] = BLYNK_AUTH_TOKEN;
char ssid[] = "iPhone";  // Nombre de tu red Wi-Fi
char pass[] = "maxpechotes";       // Contraseña de tu red Wi-Fi

BlynkTimer timer;

void setup() {
  // Inicializar la comunicación serial
  Serial.begin(9600);
  Serial.println("Iniciando comunicación serial...");
  
  // Inicialización de la comunicación serial para LiDAR
  Serial2.begin(115200, SERIAL_8N1, lidarRXPin, lidarTXPin); // Inicializar el HardwareSerial para el LiDAR

  // Configurar pines de motor y botones
  pinMode(motorStepPin, OUTPUT);
  pinMode(motorDirPin, OUTPUT);
  pinMode(finDeCarreraPin, INPUT_PULLUP);

  // Inicializar los PID
  frenadoPID.SetMode(AUTOMATIC);
  velocidadPID.SetMode(AUTOMATIC);

  // Conectar a Blynk
  Blynk.begin(auth, ssid, pass);

  // Configurar el temporizador de Blynk
  timer.setInterval(100L, controlarBlynk);  // Llamar a la función cada 100 ms
}

void loop() {
  Blynk.run();  // Mantener la conexión de Blynk activa
  timer.run();  // Ejecutar funciones del temporizador
}

// Función que se llama periódicamente para controlar Blynk
void controlarBlynk() {
  // Controlar el crucero automático
  if (controlDeCrucero) {
    // Sensar velocidad actual y aplicar PID para aceleración
    velocidadActual = medirVelocidad();
    inputVel = velocidadActual;
    velocidadPID.Compute();

    // Sensar distancia y aplicar frenado
    inputDist = medirDistanciaLidar();
    setPointDist = calcularDistanciaSegura(selectedSpeed); // Calcular la distancia de frenado segura
    frenadoPID.Compute();
    aplicarFrenado(outputFreno); // Aplicar frenado proporcional
  }
}

// Función para medir la velocidad actual (sensor infrarrojo)
int medirVelocidad() {
  // (Implementación de sensor infrarrojo)
  return velocidadActual;
}

// Función para medir la distancia con el sensor LiDAR
int medirDistanciaLidar() {
  // (Implementación del sensor LiDAR)
  return dist;
}

// Función para aplicar el frenado
void aplicarFrenado(double fuerzaFrenado) {
  if (fuerzaFrenado > 0) {
    digitalWrite(motorDirPin, HIGH); // Dirección de frenado
    for (int i = 0; i < stepsPerRevolution * (fuerzaFrenado / avancePorVuelta); i++) {
      digitalWrite(motorStepPin, HIGH);
      delayMicroseconds(slowSpeed);
      digitalWrite(motorStepPin, LOW);
      delayMicroseconds(slowSpeed);
    }
  }
}

// Función para resetear el freno
void resetFreno() {
  digitalWrite(motorDirPin, LOW); // Dirección para soltar el freno
  for (int i = 0; i < stepsPerRevolution * (maxFreno / avancePorVuelta); i++) {
    digitalWrite(motorStepPin, HIGH);
    delayMicroseconds(fastSpeed);
    digitalWrite(motorStepPin, LOW);
    delayMicroseconds(fastSpeed);
  }
}

// Función para calcular la distancia de frenado segura según la velocidad
int calcularDistanciaSegura(int velocidad) {
  if (velocidad > maxSpeed) velocidad = maxSpeed;
  return distanciasSeguras[velocidad];
}

BLYNK_WRITE(V1) {
  selectedSpeed = param.asInt(); // Obtener la velocidad seleccionada desde Blynk
}

BLYNK_WRITE(V2) {
  controlDeCrucero = param.asInt(); // Activar/desactivar control de crucero
}

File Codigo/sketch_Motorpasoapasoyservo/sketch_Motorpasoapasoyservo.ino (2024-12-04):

// Objetos
AccelStepper stepper(AccelStepper::DRIVER, stepPin, dirPin); 
Servo servo;                                                
BlynkTimer timer;

// Parámetros del motor paso a paso
const float maxSpeed = 10000.0;         
const float maxAcceleration = 5000.0;  
const int stepsPerRevolution = 6400;   
const int vueltasFreno = 6;            

// Funciones de control del motor paso a paso
void aplicarFrenado() {
  stepper.setMaxSpeed(maxSpeed);
  stepper.setAcceleration(maxAcceleration);
  int pasos = vueltasFreno * stepsPerRevolution; 
  stepper.moveTo(pasos);
  stepper.runToPosition();
}

void resetFreno() {
  stepper.setMaxSpeed(maxSpeed);
  stepper.setAcceleration(maxAcceleration);
  stepper.moveTo(0);
  stepper.runToPosition();
}

// Control del servo
void controlarServo(int angulo) {
  servo.write(angulo);
}

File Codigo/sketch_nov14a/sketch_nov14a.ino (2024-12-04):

#define BLYNK_TEMPLATE_ID "TMPL2qhiOVqKL"
#define BLYNK_TEMPLATE_NAME "Esp32"
#define BLYNK_AUTH_TOKEN "z_WQQExctXxZYm90cLcXuyi1n2bwjFtm"

#include <AccelStepper.h>
#include <ESP32Servo.h>
#include <WiFi.h>
#include <BlynkSimpleEsp32.h>
#include <PID_v1.h>

// Pines físicos
const int stepPin = 19;       // Pin de paso del motor paso a paso (freno)
const int dirPin = 25;        // Pin de dirección del motor paso a paso
const int buttonPin = 14;     // Pin del fin de carrera para resetear freno
const int speedSensorPin = 5; // Pin del sensor infrarrojo de velocidad
const int lidarRXPin = 16;    // Pin RX del sensor LiDAR
const int lidarTXPin = 17;    // Pin TX del sensor LiDAR
const int servoPin = 18;      // Pin del servo
const int ledPin = 2;         // LED integrado (GPIO 2)

// Blynk
char auth[] = BLYNK_AUTH_TOKEN;
char ssid[] = "Cooperadora Profesores";
char pass[] = "Profes_IMPA_2022";

// Objetos
AccelStepper stepper(AccelStepper::DRIVER, stepPin, dirPin); // Motor paso a paso
Servo servo;                                                // Servo
BlynkTimer timer;

// PID
double velocidadDeseada = 0;    // Velocidad seleccionada (en km/h)
double velocidadActual = 0;    // Velocidad medida (en km/h)
double salidaPID = 90;         // Salida del controlador PID (ángulo del servo)

// *Valores iniciales ajustados para PID*
// Nota: Estos valores son aproximados. Ajustarlos según las pruebas.
double Kp = 1.5; // Proporcional: Respuesta inicial al error (más alto, más rápido responde)
double Ki = 0.5; // Integral: Corrige errores acumulados (aumenta suavidad, pero puede oscilar)
double Kd = 0.2; // Derivativo: Suaviza cambios rápidos (reduce oscilaciones)

// Instancia del controlador PID
PID miPID(&velocidadActual, &salidaPID, &velocidadDeseada, Kp, Ki, Kd, DIRECT);

// Parámetros
const float maxSpeed = 10000.0;          // Velocidad del motor paso a paso en pasos por segundo
const float maxAcceleration = 5000.0;   // Aceleración del motor paso a paso
const int stepsPerRevolution = 6400;    // Micropasos por revolución (DM556)
const int vueltasFreno = 6;             // Avance fijo del freno en vueltas completas
const int distanciasSeguras[] = {0, 30, 54, 63, 72, 81, 121, 187, 204, 221, 238, 
                                  330, 418, 444, 470, 496, 606}; // Distancias mínimas seguras

// Variables de estado
bool sistemaActivado = false;
unsigned long pulsosSensor = 0;
float distanciaActual = 0;
bool finDeCarreraActivado = false;

// Función para medir velocidad
void medirVelocidad() {
  static unsigned long tiempoAnterior = 0;
  unsigned long tiempoActual = millis();
  if (digitalRead(speedSensorPin) == LOW) { // Sensor detecta pulso
    pulsosSensor++;
    if (pulsosSensor % 14 == 0) { // Cada 14 pulsos corresponde a 138 cm
      float distancia = 1.38; // 138 cm en metros
      float tiempo = (tiempoActual - tiempoAnterior) / 1000.0; // Tiempo en segundos
      velocidadActual = (distancia / tiempo) * 3.6; // m/s a km/h
      tiempoAnterior = tiempoActual;
    }
  }
}

// Función para medir distancia con LiDAR
void medirDistanciaLidar() {
  if (Serial2.available() > 0) {
    distanciaActual = Serial2.read(); // Lee la distancia medida por LiDAR
  }
}

// Función para frenar
void aplicarFrenado() {
  stepper.setMaxSpeed(maxSpeed);
  stepper.setAcceleration(maxAcceleration);
  int pasos = vueltasFreno * stepsPerRevolution; // 6 vueltas completas
  stepper.moveTo(pasos);
  stepper.runToPosition();
}

// Función para resetear freno
void resetFreno() {
  stepper.setMaxSpeed(maxSpeed);
  stepper.setAcceleration(maxAcceleration);
  stepper.moveTo(0);
  stepper.runToPosition();
}

// Control del servo
void controlarServo(int angulo) {
  servo.write(angulo);
}

// Control de crucero con PID
void controlarCrucero() {
  medirVelocidad();
  medirDistanciaLidar();

  if (sistemaActivado && !finDeCarreraActivado) {
    // Calcula la salida del PID
    miPID.Compute();

    // Ajusta el servo según la salida del PID
    controlarServo(salidaPID);

    // Frenado en caso de emergencia por LiDAR
    int distanciaSegura = distanciasSeguras[(int)velocidadDeseada];
    if (distanciaActual < distanciaSegura) {
      controlarServo(80); // Deja de acelerar
      aplicarFrenado();   // Activa el freno
    }
  }
}

// Blynk
BLYNK_WRITE(V0) {
  sistemaActivado = param.asInt();  // Actualiza el estado del sistema
  if (sistemaActivado == 1) {
    digitalWrite(ledPin, HIGH);  // Enciende el LED cuando V0 es 1
    controlarServo(80));          // El servo se mueve a la posición inicial (90 grados)
  } else {
    digitalWrite(ledPin, LOW);   // Apaga el LED cuando V0 es 0
    controlarServo(0);           // El servo se mueve a la posición opuesta (0 grados)
    resetFreno();
  }
}

BLYNK_WRITE(V1) {
  velocidadDeseada = param.asInt(); // Actualiza la velocidad deseada
}

void setup() {
  Serial.begin(115200);
  Serial2.begin(115200, SERIAL_8N1, lidarRXPin, lidarTXPin);

  pinMode(speedSensorPin, INPUT_PULLUP);
  pinMode(buttonPin, INPUT_PULLUP);
  pinMode(ledPin, OUTPUT); // Define el pin del LED como salida

  stepper.setMaxSpeed(maxSpeed);
  stepper.setAcceleration(maxAcceleration);
  servo.attach(servoPin);

  miPID.SetMode(AUTOMATIC);            // Activa el modo automático del PID
  miPID.SetOutputLimits(0, 180);       // Limita la salida a los ángulos del servo

  Blynk.begin(auth, ssid, pass);
  timer.setInterval(100L, controlarCrucero);
}

void loop() {
  Blynk.run();
  timer.run();

  if (digitalRead(buttonPin) == LOW) {
    finDeCarreraActivado = true;
    sistemaActivado = false; // Apagar el sistema
    Blynk.virtualWrite(V0, 0); // Actualizar en la app Blynk
    digitalWrite(ledPin, LOW); // Asegura que el LED se apague
  }
}

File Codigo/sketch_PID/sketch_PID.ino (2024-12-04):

// PID
double velocidadDeseada = 0;    
double velocidadActual = 0;    
double salidaPID = 90;         

// *Valores iniciales ajustados para PID*
double Kp = 1.5; 
double Ki = 0.5; 
double Kd = 0.2; 

PID miPID(&velocidadActual, &salidaPID, &velocidadDeseada, Kp, Ki, Kd, DIRECT);

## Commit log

2024-10-25 Create Banner (90 x 120 cm).png
2024-11-07 Document: Manual de Usuario Español
2024-11-14 Document: Carpeta de campo Hasta Abril
2024-11-14 Update: Carpeta de campo
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2024-11-14 Update: Codigo
    Tratando de realizar conexion de la interfaz "Blynk" con la esp32 para manejar el carro desde el celular
2024-11-14 Update: Codigo
    Una vez aprendi a realizar la conexion del blynk a la esp32 ya puedo manejarla mediante la red Cooperadora Profesores desde mi celular
2024-11-14 Update: Codigo
    Este codigo ya esta apto para probar en el carro funcionando,
2024-11-15 docss: pcb placa madre
2024-11-15 docss: pcb planchado en placa de cobre
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2024-11-15 docss: cableado de luces
2024-11-15 Create Imagen de WhatsApp 2024-11-14 a las 22.21.11_4e007d52.jpg
2024-11-15 Create Imagen de WhatsApp 2024-11-14 a las 22.21.11_85924f6f.jpg
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2024-11-15 Create Imagen de WhatsApp 2024-11-14 a las 22.43.56_6ac86141.jpg
2024-11-15 Update: Pagina web
    Creacion y Configuracion de la barra de navegacion/Botones para usar en la pagina
2024-11-15 Update: Pagina Web
    adjunto foto de la seccion ¿Por Que Elegirnos?
2024-11-15 Update: Pagina Web
    Adjunto foto de la seccion ¿Como Surge esta idea?
2024-11-15 Update: Pagina Web
    Adjunto foto de la seccion integrantes
2024-11-15 Update: Pagina web
    Adjunto Javascript de la pagina
2024-11-15 Create Linktree
    Añadir link hacia el linktree
2024-11-15 Create CanalYT
    Añadir link de YT
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2024-11-15 Create Video de WhatsApp 2024-11-14 a las 22.56.18_beaa715d.mp4
    Docss: conexion de la controladora
2024-11-15 Docss: Armado de opticas
2024-11-15 docs: presupuesto cooperadora
    [Presupuesto cooperadora.xlsx]
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2024-11-16 Docss: conexion tablero de luces
2024-11-16 Docss: tablero de luces
2024-11-16 Docss: Esquematico pwm arreglando errores
2024-11-16 Docss: PCB con modificaciones
2024-11-16 Create Placa PWM 16.11.24.pdf
2024-11-16 Docss: Modelo 3D PWM modificado
2024-11-17 Docs: Presupuesto Alumnos
    [Presupuesto alumnos.xlsx]
2024-11-17 Docs: Facturas de Compras
2024-11-17 Delete: Documento Manual de Usuario
2024-11-17 Docs: Documento Manual de Usuario
2024-11-17 Delete: Document Manual de Usuario
2024-11-17 Fix: Manual de Usuario
2024-11-19 Docs: Presupuesto Alumnos
    Se agregaron unos componentes comprados hoy.
    [Presupuesto alumnos.xlsx]
2024-11-19 Docs: Facturas de Compras
    Se agrega factura de compra del día de hoy.
2024-11-20 Fix: Manual de Usuario
    Manual de Usuario Version Final
2024-11-20 Created: Carros Melex
    Se crea carpeta para organizar la documentacion de los carros Melex.
2024-11-30 Docss: Datasheets Mosfet Irf1407
2024-12-03 Docss: Instalación de motor paso a paso
2024-12-03 Docss: Modificación del eje del freno para poder usar el motor
2024-12-03 Docss: Cambiado de fusibles
2024-12-03 Docss: Cambiar varilla y purgado de frenos
2024-12-03 Docss: Purgado de frenos
    Purgado de frenos y cambio de varilla de liquido de freno de ruedas traseras
2024-12-03 Docss: Revision y Cambiado de fusibles
2024-12-03 Docss: Medicion con el osciloscopio
    Medicion con el osciloscopio octoacoplador
2024-12-03 Docss: Instalación servo para accionar el acelerador
2024-12-04 Funcionalidad: Configuración del controlador PID.
2024-12-04 Funcionalidad: Medición de velocidad y distancia.
2024-12-04 Funcionalidad: Control de crucero con frenado automático.
2024-12-04 Integración: Configuración de Blynk y control del sistema.
2024-12-04 Create: prueba de frenado CARRITO 1
2024-12-04 Update: Prueba de frenado 2
2024-12-04 Update: Configuracion de pines y librerias
2024-12-04 Update: Pruebas de frenado
2024-12-04 Update: Paso a paso y servo
2024-12-04 Update:Configuracion
    Inicialización: Configuración de pines y bibliotecas básicas.
2024-12-04 Update: Medicion del Sensor lidar
2024-12-04 Update: CABLEADO DEL VEHICULO PARTE 1
2024-12-04 Update: CABLEADO DEL VEHICULO PARTE 2
2024-12-04 update: cableado parte 2 vehiculo 1.jpg
2024-12-05 update: diseño de pieza 3d
    [Pieza 3d Caja protector de placa.stl, Stunning Duup-Jaiks.stl]
2024-12-05 Create: Bomba de freno
2024-12-05 Update: Desarmado bomba de freno
2024-12-05 Update: Armado de bomba de freno
2024-12-05 Desarmado de bomba de freno parte 2
2024-12-06 Create: Colocacion de disco segmentado
2024-12-06 create: Desarmado de la controladora
2024-12-06 update: desarmado de controladora
2024-12-06 create: soporte de tuerca para freno
2024-12-06 update: soporte para la tuerca de freno 1
2024-12-06 update: soporte de tuerca para freno 2
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2024-12-06 update: prueba de estimacion de fuerza para el pedal de freno
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2024-12-10 chore: arreglo lo que rompio Thiago
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2024-12-11 Update: lm2596
    Este componente lo usamos para reducir el voltaje de las baterias (48V) y usarlo en otros componentes
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2024-12-12 Update: Datos motor carrito Melex
    Aca estan las especificaciones del motor, cuanto pesa (25,02 K) , el voltaje (48) etc
2024-12-12 Update: MLX90819
    Encoder velocímetro o tacómetro: sirve para medir las vueltas de la rueda y poder calcular la velocidad
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2024-12-14 Update: Armado de la controladora con el circuito PWM
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2024-12-14 Update: Armado del Solenoide con el nuevo PWM
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
